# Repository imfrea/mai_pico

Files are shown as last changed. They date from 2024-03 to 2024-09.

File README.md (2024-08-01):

# Mai Pico - Maimai Style Mini Controller
### The purpose of this fork is to provide more detailed production documents, material lists, and casing designs (in Chinese language).
[点这里可以切换到中文版](README_CN.md)

  


**Features:**
* Made with a 15.6 inch portable screen.
* Arcade-like experience.
* Dual-player is possible.
* Built-in AIME support.
* All source files open.

Thanks to many respectful guys/companies who made their tools or materials free or open source (KiCad, OnShape, InkScape, Raspberry things, JLCPCB).

## Notes
This project is the most complex one among all my projects.
* It needs a custom etched ITO glass and a portable display.
* Heavily depends on 3D printing.
* Requires skills to solder tiny components.
* Requires many other DIY hands-on skills.
* The IO PCB is still in prototype state, it works, but the layout and connectors are not perfect. You may need to solder directly from Pi Pico's pins. I'm just too lazy to release a new version.
* I didn't design the housing, so it's your job to make it look nice and structually stable, follow your imagination and taste.

## Check Out My Other Projects
You can also check out my other cool projects.










* Popn Pico: https://github.com/whowechina/popn_pico
* IIDX Pico: https://github.com/whowechina/iidx_pico
* IIDX Teeny: https://github.com/whowechina/iidx_teeny
* Chu Pico: https://github.com/whowechina/chu_pico
* Mai Pico: https://github.com/whowechina/mai_pico
* Diva Pico: https://github.com/whowechina/diva_pico
* AIC Pico: https://github.com/whowechina/aic_pico
* Groove Pico: https://github.com/whowechina/groove_pico

## **Disclaimer** ##
I made this project in my personal time with no financial benefit or sponsorship. I will continue to improve the project. I have done my best to ensure that everything is accurate and functional, there's always a chance that mistakes may occur. I cannot be held responsible for any loss of your time or money that may result from using this open source project. Thank you for your understanding.

## About the License
It's CC-NC. So DIY for yourself and for your friend, don't make money from it.

## Builds Gallery
Before we start, I want to encourage you with some hobbyist builds.

### **Lavide's Build**
  Lavide made a nice compact all-in-one Mai Pico cab!  
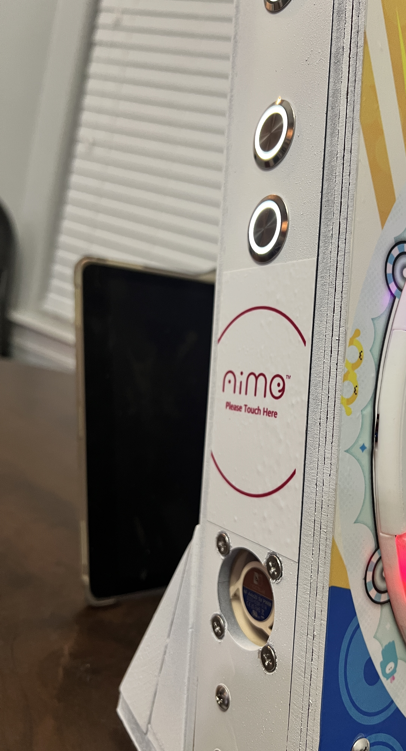
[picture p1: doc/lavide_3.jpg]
  

### **Romper's Build**
  Romper made a full-size con using Mai Pico's touch design.  
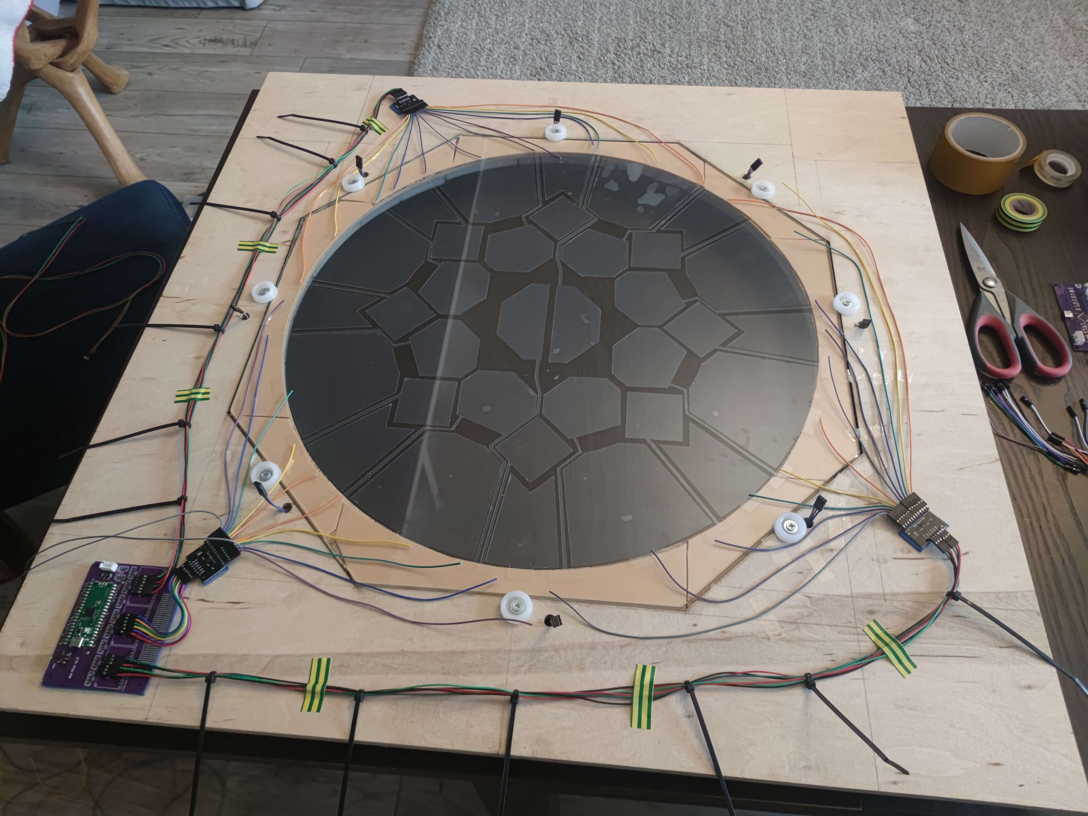
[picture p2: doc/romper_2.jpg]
    
  Check out his build guide here.  
  https://github.com/ir0nq/maimai-homemade-controller

### **imfrea's Build**
  imfrea designed a nice-looking and inexpensive acrylic housing for Mai Pico.  
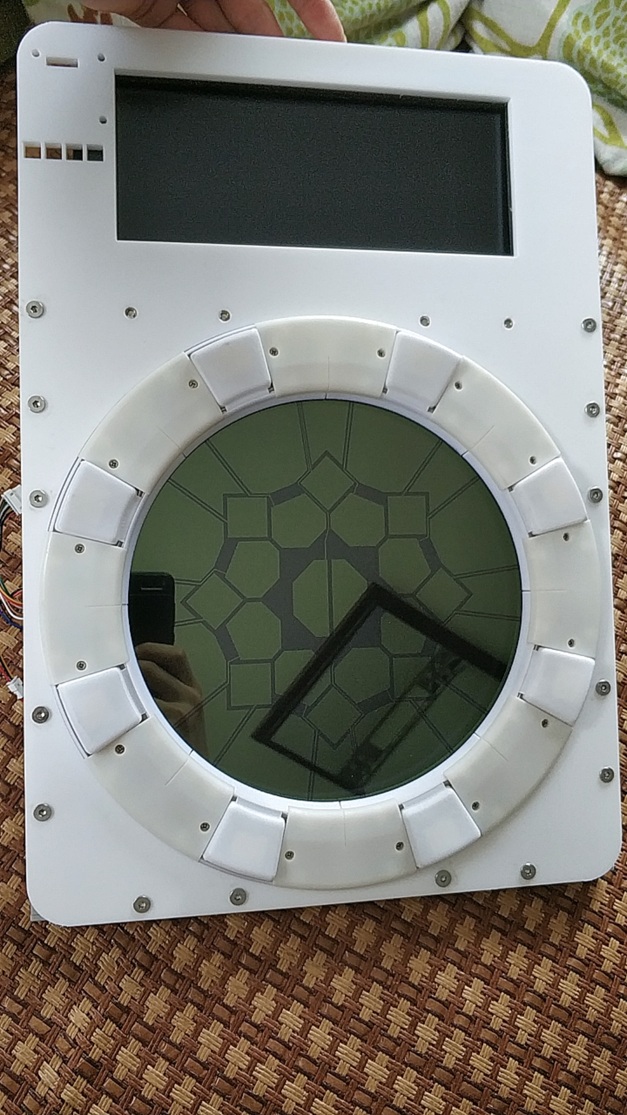
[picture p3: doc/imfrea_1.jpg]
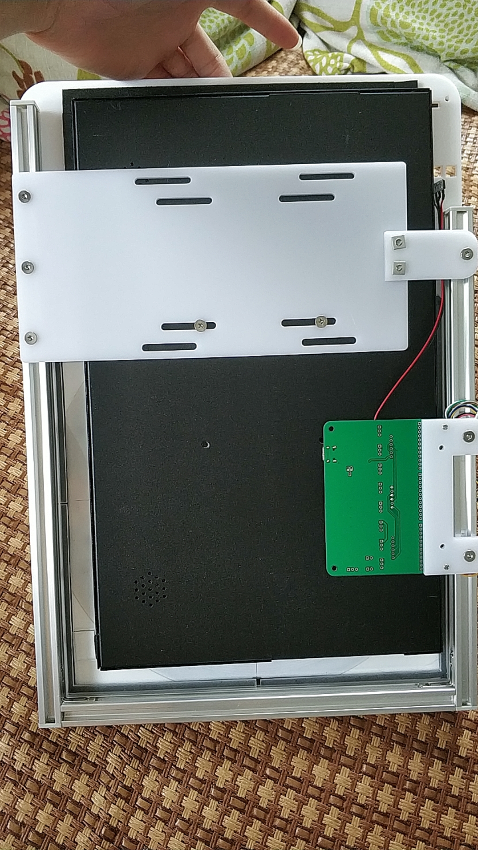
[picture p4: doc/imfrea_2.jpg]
    
  You can download the acrylic case designs from his fork of Mai Pico here.  
  https://github.com/imfrea/mai_pico

## HOW TO BUILD
### PCB
* Go JLCPCB and make order with the gerber zip file (latest `Production\PCB\mai_io_v*.zip` and `Production\PCB\mai_button_v*.zip`), regular FR-4 board, 1.6mm thickness. You need 1x io PCB and 8x button PCBs for one Mai Pico con.  
  
* 1x Rasberry Pico Pi Pico or Pico W.  
  https://www.raspberrypi.com/products/raspberry-pi-pico
  Becareful of 3 pins that are at the other side, they're difficult to solder and may leave air bubbles.  
  
* 1x USB Type-C socket (918-418K2023S40001 or KH-TYPE-C-16P)
* 2x 0603 5.1kohm resistors (R20, R21) for USB. If you plan to use the native USB socket on the Pi Pico directly, then the Type-C socket and resistors can be omitted, making the soldering much simpler.
* 3x MPR121 modules, there're many types in the market, choose ones like this.  
  https://www.sparkfun.com/products/retired/9695  
  Before solder MP121 module to the main PCB board, remember to use a knife to **cut (unshort) the tiny trace that connects ADDR to the GND**. Please be careful not to cut more than necessary.  
  
* Leave U5, U6, U7 area discrete components empty as we're using MPR121 module, not the chip.
* 1x SN74LV1T34DBVR (SOT-23-5) level shifter (U8), if you can't find one, use a 0603 10ohm resistor (R4) as an alternative.  
  https://www.lcsc.com/product-detail/Buffer-Driver-Transceiver_Texas-Instruments-SN74LV1T34DBVR_C100024.html
* 4x 0603 1uF (0.1~1uF all fine) capacitors (C1, C2, C3, C7), OPTIONAL, recommended.
* 16x WS2812B-3528 RGB LEDs (each button needs two).
* 8x Kailh Choc v1 key switches, linear, 30gf to 45gf ones.  
  https://www.kailhswitch.com/mechanical-keyboard-switches/low-profile-key-switches/burnt-orange-switch.html
* 1x PN532 NFC module and some thin wires, only needed if you want AIME.  
  https://www.elechouse.com/product/pn532-nfc-rfid-module-v4/  
  You need to solder it to the same I2C as the MPR121 (GPIO 6 and 7).

### ITO Glass
* Find a service to make custom etching ITO coated glass. The AutoCAD file is `Production\CAD\mai_pico_ito_v*.dwg`. Use 2mm thickness, 10-20ohm sheet resistance ITO coated glass.
  
* The ITO coated glass is connected to the IO PCB by "zebra cable" (1.6mm pitch: 0.8mm black part and 0.8mm clear part). A silicon heater head at 200°C is used to stick the zebra cable to the gold finger part of PCB and ITO coated glass. The formal name of this cable is "Heat Seal Connector".  
  
* Custom ITO coated glass is relatively expensive, but ours is small, so it's not like arcade-size expensive. This is the shop I ordered the ITO glass. The minimal batch is around 5 pieces. But they provide service only in China as far as I know.  
  https://shop378788148.taobao.com/?spm=2013.1.1000126.2.305e16c4LFf1GW

### Button Ring
* Print out the 8x set of base, link, button and cover from `Production\3DPrint\mai_*.stl`.
* Buy 8x 2mm (diameter) * 40mm (length) steel shafts, they're used as the button hinge.
* Here's how to assemble them, hinge shaft and components on PCB are not shown in this rendered image.  
  
* Here's how I assembled the ring. Please note that wiring for the button switches is missing in these pictures.
  * All discrete components ready.  
    
  * Solder the button PCB first.  
    
  * Button PCBs are daisy-chained using short and soft 3-wire cable, they're G, IN/OUT, V (GND, Signal In/Out and VCC respectively). RGB signal goes in from "IN" and goes out to the next LED through "OUT". The "Btn" button signal pins are not soldered yet, you can later wire them. Don't worry about the order of button GPIOs, because they can be remapped through command line interface.    
    
  * You need 3M5423 UHMW film tape (or similar hard and super-smooth PTFE tape with 0.2-0.3 thickness). It is to lubricate the button surface that touches the keyswitch.  
    
  * Assemble the 3D printed parts together with the PCBs.  
    
  * Use shaft to expand the support holes a little bit, and apply some keyboard switch lubricant such as Krytox 205G0 to make the shaft super smooth.  
    
  * Each `link` needs 8x M2*4mm screws to connect two `base`s together.  
    
  * Install the cover, each needs 2x M2*5mm screws.  
    

### Portable Display
  * Resolution: 1920*1080, size: 15.6inch, refresh rate: 120Hz (recommended) or 60Hz, built-in speakers.
  * They're easy to find. Choose cheap or even tiny-flawed ones, they're much cheaper and work just fine.
  * There're 2 types of driver board, one is micro-HDMI only and the other supports type-C display (for convenient Nintendo Switch connection). They're both OK.  
  https://www.amazon.com/s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

### Glue Things Together
  * I use 3M VHB tape (0.5mm or 1mm thickness) to stick the button ring, the ITO glass and the monitor together.
  * Only use a little tape, I use 4 small pieces to stick ITO glass to the display and another 4 small pieces to stick button ring to the ITO glass.
  * Don't apply the tape on the traces of the ITO glass, you can see the traces or pads at certain angle.

### Housing
  * It's your job to design it and make it look nice.

### Firmware
* UF2 file is in `Production\Firmware` folder.
* For the new build, hold the BOOTSEL button while connect the USB to a PC, there will be a disk named "RPI-RP2" showed up. Drag the UF2 firmware binary file into it. That's it.
* LED and Touch protocols are implemented following Sucareto's research at https://github.com/Sucareto/Mai2Touch.
* It has a command line to do configuration. You can use this Web Serial Terminal to connect to the USB serial port of the Mai Pico. (`?` to display help message.)  
  https://googlechromelabs.github.io/serial-terminal/  
  
   * Please note that when you click "Connect" button, you'll actually see the name of each port.  
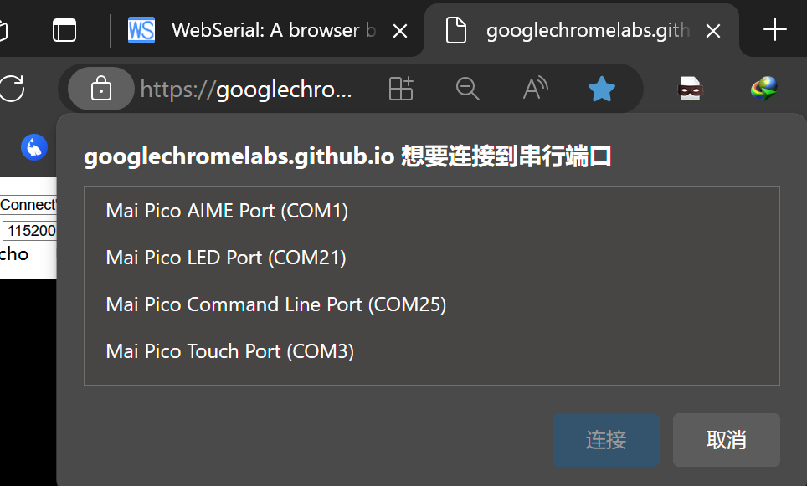
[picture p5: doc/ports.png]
   
* Button GPIOs can be remapped using `gpio` command. Firmware supports 8 main buttons on the ring and 4 auxiliary buttons (Test, Service, Navigate and Coin).
* Touch keys can be remapped using `touch` command. For people who's using Mai Pico to drive a custom ITO film or a ITO glass, this command will be very useful. For example:
  * `touch` with no parameter is to detect touched keys.
  * `touch 1 9 E6` is to set the second MPR121's electrode 9 to key "E6". Key name of "XX" means "Not Connected".
* Daisy chained RGB LED numbers for each button can be assigned using `rgb` command.
* LED brightness can be adjusted by `level` command.
* There are MPR121 parameter tuning and sensitive settings, explore them yourself.
* It implements 3 COM ports, one is for command line and the other two are for LED and Touch. By issuing `whoami` to the command line, each COM port will print their identities.
* Button signal is sent to the host by HID Joystick or HID NKRO (keyboard). There're two set of NKRO keymaps, use `hid <joy|key1|key2>` to switch between them. In NKRO mode, key mappings are:
  * key1: `WEDCXZAQ`-Ring Buttons, `3`-Select
  * key2 (Numpad): `89632147`-Ring Buttons, `*`-Select
  * Above two sets both have: `F1`-Test `F2`-Service `F3`-Coin
* `factory` to reset to default. When there's a firmware update, the old configuration may become corrupted, you can reset configuration, then re-plug the controller.

## CAD Source File
I'm using OnShape free subscription. It's powerful but it can't archive original designs to local, so I can only share the link here. STL/DXF/DWG files are exported from this online document.  
https://cad.onshape.com/documents/d8b39d27c9cb7990d9ce4d46/w/2c1baa71e391bfd1246f122b/e/f87f0f1c373fe2186ddc5c9c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

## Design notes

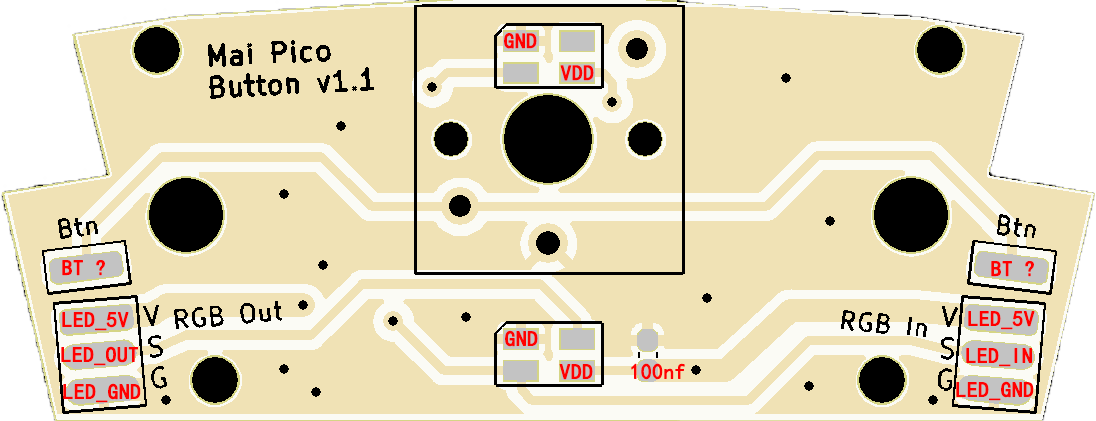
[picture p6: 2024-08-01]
doc/button_v111_top.png

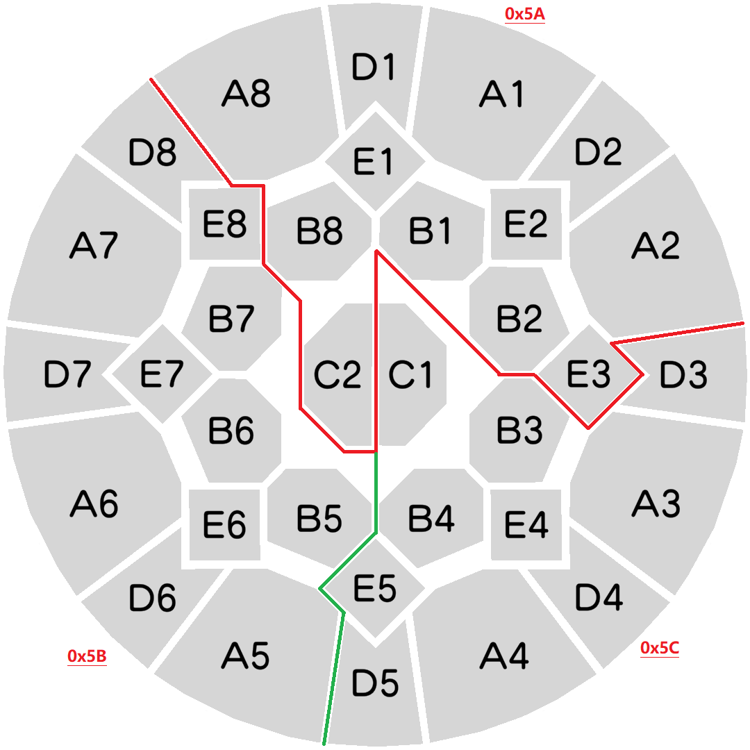
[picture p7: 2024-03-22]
doc/mpr121_electrode.png

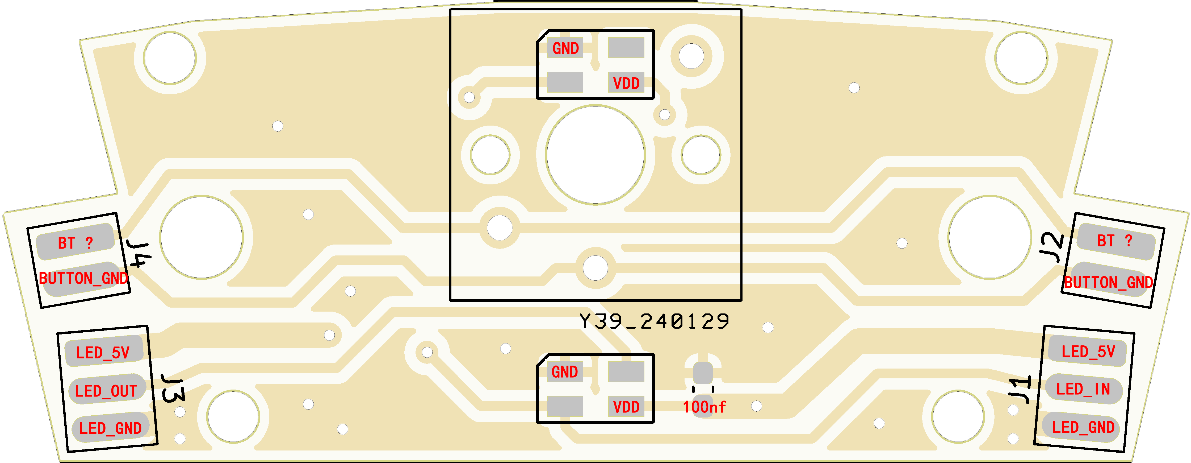
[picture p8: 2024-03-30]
doc/button_v1_top.png

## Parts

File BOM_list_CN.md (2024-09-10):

### 物料清单

* 电子元件部分

| 序号 | 名称 | 规格 | 库位 | 所需数量 | 参考价格 | 重要性 | 备注 |
| ---- | --- | --- | --- | --- | --- | --- | --- |
| 1 | mai_io_v1  PCB | FR-4  2层 1.6mm厚 | | 1 | 20￥/5片 | 必要 | 不需要确认生产稿\|单片出货\|添加嘉立创客编-无要求\|不需要SMT贴片\|不需要开钢网 |
| 2 | mai_button_v111  PCB  | FR-4  2层 1.6mm厚 白色阻焊 | | 8 | 25￥/10片 | 必要 | 同上，其余选项请保持默认 |
| 3 | 树莓派 Pico | 不焊接排针 | U1 | 1 | 15.8￥/片 | 必要 | 购买无后缀的Pico，除非你正好有Pico W |
| 4 | Type-C母座 | 918-418K2023S40001 / KH-TYPE-C-16P | USB1 | 1 | 0.23￥/颗 | 可选 | 别名：16p贴片 4脚直插 |
| 5 | 5.1k 电阻 | 0603 精度5%或1%均可 | R20 R21 | 2 | 0.8￥/100颗 | 可选 | |
| 6 | MPR121 模块 | | U5 U6 U7 | 3 | 14.7￥/3片 | 与MPR121芯片**二选一** | |
| | 2.54mm 短排针 | 7.5mm 单排 6Pin 与12Pin | | 3+3 | 5.5￥/6Pin 12Pin各10个（或仅12Pin*12个） | 可选，与MPR121芯片**二选一** | MPR121模块附带的排针较长，可剪短，或额外购买短排针 |
| 7 | MPR121QR2 芯片 | QFN20 | U2 U3 U4 | 3 | 6.39￥/3颗 | 与MPR121模块**二选一** | 用于分立电路 |
| 8 | 75k 电阻 | 0603 | R1 R2 R3 | 3 | 0.8￥/100颗 | 与MPR121模块**二选一** | 用于分立电路 |
| 9 | 0.1uF 电容 | 0603 耐压16V（以上） 精度±10% | C4 C5 C6 C8 C9 C10 | 6 | 1.5￥/50颗 | 与MPR121模块**二选一** | 用于分立电路 |
| 10 | 0.1uF 电容 | 0603 | C1 C2 C3 C7 | 4 | 占位，勿重复购买 | 可选（推荐） | 别名：100nf 104 |
| 11 | 10r 电阻 | 0603 | R4 | 1 | 0.8￥/100颗 | 可选（与SN74LV1T34**二选一**） | |
| 12 | SN74LV1T34DBVR 芯片 | SOT-23-5 | U8 | 1 | 0.49/颗 | 可选（与10r电阻**二选一**） | |
| 13 | 0.1uF 电容 | 0603 | | 8 | 占位，勿重复购买 | | 用于按键板 |
| 14 | WS2812B  RGB LED | 3528 | | 16 | 2.54￥/16颗 | | 注意是**3528**封装，型号WS2812B，而非普通RGB灯珠 |
| 15 | 凯华 Choc v1 轴体 | 线性 30gf 到 45gf | | 8 | 28￥/10颗 | | 别名：巧克力 v1 猪鼻 白轴 矮轴（描述词有差异 以实物图片为准） |
| | NFC模块 | PN532 | | 1 | 12.4￥/片 | 可选 | |

* 结构件与五金件

| 序号 | 名称 | 规格 | 所需数量 | 参考价格 | 重要性 | 备注 |
| ---- | --- | --- | --- | --- | --- | --- |
| 16 | mai_base.stl | | 8 | 同下 | | **慎用SLA光固化工艺**，推荐FDM（层高小于0.2mm）ABS或PETG材料获得最佳性价比与强度 |
| 17 | mai_link.stl | | 8 | 同下 | | **慎用SLA光固化工艺**，推荐FDM（层高小于0.2mm）ABS或PETG材料获得最佳性价比与强度 |
| 18 | mai_button.stl | | 8 | 同下 | | **慎用SLA光固化工艺**，同上，可选SLS激光烧结白色尼龙，可获得更好的表面纹理与强度 |
| 19 | mai_cover.stl  | | 8 | 62￥/本项加以上共32件（ABS） | | 可选SLA光固化工艺，获得最佳的表面纹理与性价比 |
| 20 | 钢轴 | 2mm（直径）* 40mm（长度） | 8 | 2.29￥/50颗 | | 别名：不锈钢销钉 |
| 21 | M2*4mm 螺丝 | | 64 | 1￥/100颗 | | 用于打印件mai_link的安装 |
| 22 | M2*6mm 螺丝 | | 16 | 1￥/100颗 | | 用于打印件mai_cover的安装 |

* 通用

| 序号 | 名称 | 规格 | 所需数量 | 参考价格 | 重要性 | 备注 |
| ---- | --- | --- | --- | --- | --- | --- |
| 23 | ITO 玻璃 | 2mm厚  10-20欧姆方阻 | 1 | 126￥/片 | 必要 | 可咨询该商家近期是否有相同订单在生产，若有，则1片也可以发货。或者到闲鱼上寻找他人多订的存货。 |
| 24 | 斑马线 | 1.6mm 间距 34Pin XX16 | 1 | 9￥/49Pin*210cm | 必要 | 别名：热压导电斑马纸 34Pin以上可**自行剪裁**，总长度建议在**5cm以内**，避免影响触摸灵敏度 |
| 25 | 一些电子线 | 不是必须得用4Pin排线，不宜太粗，28或30AWG均可，建议选择“双头镀锡电子线 4cm” | | | 必要 | 用于按键板与io板之间的连接 |
| 26 | 空中对接线 | 1.25mm  3pin母头+端子线 | 一对 | 3.3￥/5+5条（10cm）  | 可选 | 用于按键板与io板之间的连接 |
| 27 | 空中对接线 | 1.25mm  8pin母头+端子线 | 一对 | 3.33￥/1+1条（15cm） | 可选 | 用于按键板与io板之间的连接 |
| 28 | 成品便携屏（含驱动板） | 分辨率：1920*1080，尺寸：15.6 英寸，刷新率：120Hz（推荐）或 60Hz，内置扬声器。micro-HDMI或Type-C显示接口。 | 1 | | 必要 | 你也可以从头DIY一个15.6寸显示器，本文不详细讨论。如果你有180°开合或360°翻转的15.6寸屏笔记本电脑，若无冲突亦可直接安装于上。 |

* 工具与辅料

| 序号 | 名称 | 规格 | 所需数量  | 参考价格 | 重要性 | 备注 |
| ---- | --- | --- | --- | --- | --- | --- |
| 29 | T型烙铁头（烙铁套装）+橡胶条 | | 1套 | 9.9￥/套 | 必要 | 别名：斑马线热压头 请选择适合自己烙铁的类型，或带烙铁的套装 |
| 30 | 3M5423  UHMW或 PTFE 胶带 | 厚度 0.2-0.3 | 1卷 | | | 用于填充键帽与轴体的空隙（无铺垫材料可能无法触发全部键程）  |
| 31 | 3M VHB 胶带 | | 1卷 | | | 用于粘接按钮环、玻璃以及显示器 |
| 32 | 纤维胶带 | 12mm宽 | 1卷 | | | 用于保护io PCB与玻璃间的斑马线 |
| 33 | 醋酸胶带 | 10mm宽 | 1卷 | 2.16￥/30米 | | 用于包裹ITO玻璃的边缘 |
| 34 | 润滑脂 | Krytox 205G0 | 1罐/盒/瓶 | | | |

* 工具与辅料（未提及）

| 序号 | 名称 | 重要性 | 备注 |
| ---- | --- | --- | --- |
| 41 | 电烙铁 | 必要 | 又称焊台，推荐恒温可调内热式，刀头 |
| 42 | 热风枪 | 可选 | 便于焊接贴片元器件（与PTC发热板二选一） |
| 43 | PTC发热板 | 可选 | 又称LED灯珠拆焊台，便于焊接贴片元器件（与热风枪二选一） |
| 44 | 尖头镊子 | 必要 | 用于夹持小型元器件 |
| 45 | 美工刀 | | 剪裁胶带等 |
| 46 | 斜口钳/剥线钳 | | 用于剪断和剥开线缆 |
| 47 | 螺丝刀 | 必要 | |
| 48 | 万用表 | 推荐 | 用于检测线路通断等 |
| 49 | 焊锡丝 | 必要 | 含铅 63%纯度 0.8mm |
| 50 | 锡浆 | 可选 | 中温183℃，与2、3项搭配使用 |
| 51 | 助焊剂 | 可选 | |
| 52 | 电工胶带/热缩管 | | |

* 外壳（实用经济版）

`免责声明：本人为非专业人士，使用非专业软件设计此外壳，谨慎使用。因理解偏差等原因造成的损失需自行承担，使用本方案视作理解并接受。本人不对DIY成功率作任何保证，亦不提供一对一指导。`

* 本方案利用一整块亚克力激光切割而成，如厂家是按件计费的（CNC加工可能不接受板内有多个组件，或报价较高），请考虑更换厂家。
  * 亚克力的质地较软且容易产生划痕，但成本低易于加工，你也可以采用其他板材（玻纤板、PP板、PVC板等），板材的厚度也可以根据实际情况调整（注意改变板厚会同时要改变螺丝长度）

| 序号 | 名称 | 规格 | 所需数量 | 参考价格 | 备注 |
| ---- | --- | --- | --- | --- | --- |
| 1 | front.dwg 前面板 | 长409 宽282 厚4mm 白色亚克力 | 1片 | 30￥/张 | 内含其他组件1+6共7件 见`\doc\assemble_case_part.jpg` |
| 2 | mid.dwg 中框垫板 | 长292.5 宽236 厚2mm 亚克力（颜色不限） | 1片 | 10￥/张 | 共8小件 |
| 3 | 螺丝 | m4*12 薄头 | 18颗 | 3￥/50颗 | 用于前面板 |
| 4 | 1515欧标铝型材 | 银色 383.5mm | 2条 | 2.11￥/条 | 型材框 |
| 5 | 1515欧标铝型材 | 银色 252mm | 1条 | 1.39￥/条 | 型材框 |
| 6 | 1515端盖 | 灰色 | 4个 | 0.2￥/个 | 用于型材框 |
| 7 | 1515角槽（配螺丝） | | 2个 | 1￥/套 | 用于型材框（注：含4颗m4顶丝） |
| 8 | T形螺母 | 欧标15TM4 | 24颗 | 0.25￥/颗 | 用于型材框 |
| 9 | 螺丝 | m4*8 薄头 | 8颗 | 3.7￥/100颗  | 用于VESA背板及IO PCB安装板 |
| 11 | 螺丝 | m3*5 对锁螺丝 | 6对 | 4.34￥/20对  | 用于io板 PN532模块（注：子母丝成对） |
| 12 | 螺丝 | m4*6 薄头 | 8颗 | 2.93￥/100颗 | 用于前面板、与夹板螺母组合，以及VESA安装孔 |
| 13 | 夹板螺母 | m4*4 **外径5** | 6颗 | 2.38￥/20颗  | 用于前面板和VESA背板（注：仅螺母） |
| 14 | 扳手 | 2.5mm内六角 | 1把 | 1.5￥/把 | M4内六角螺丝使用，实际取决于你以上购买的螺丝类型 |
| 15 | EVA海绵胶 | 4mm厚 宽度≤20mm | 1卷 | | 用于前面板 |
| 16 | sticker.png 装饰贴纸 | 282*118mm | 1张 | | 由“[剪刀Official](https://space.bilibili.com/89636132)”设计 |

* 完整版外壳（以上表为基础）
| 序号 | 名称 | 规格 | 所需数量 | 参考价格 | 备注 |
| ---- | --- | --- | --- | --- | --- |
| 1 | back-full.dwg 背板 | 长409 宽282mm 2mm厚 玻璃纤维  | 1片 | 40￥＜ | 完整背板，兼容成品便携屏，亦支持带锁孔的液晶屏的安装 |
| 2 | cover.dwg 上框保护盖 | 长282 宽119 厚1mm 透明亚克力  | 1片 | 10￥ | 屏幕防尘和盖住贴纸 |
| 3 | 螺丝 | m4*6 薄头 | 8颗 | | 用于完整背板 |
| 4 | m2铜柱 | 双通 m2*12mm | 8颗 | | 用于带锁孔的液晶屏安装 |
| 5 | 螺丝 | m2*6 勿重复购买 | 16颗 | | 用于带锁孔的液晶屏安装 |
| 5 | EVA海绵胶 | 同上表，勿重复购买，叠2层使用 | | | 用于液晶屏底部 |

* 如果你是触屏流玩家，且不考虑制作按键环，则可以节约100￥的成本和大部分的工序（但你将同时失去灯光和圆形边框）。
  
  * 不制作按键环，以上表格中的第2，11，12，13，14，15；25，26，27，34项，表格 “结构件与五金件” 内的全部项目都无需购买。
  
* 价格可能随市场行情波动，以上报价（正常价格含邮费）仅供参考，供货商的不同，最小起订量也将不同。

* 购买电子元件，请尽量选择品类丰富齐全，价格合理的店铺，特别是运费低或包邮门槛低的店铺（减少不必要的运费损耗），但也不要一味追求一站式配齐。

  购买数量刚好覆盖需求即可，亦可适当多备几件。

* 如果你第一次使用嘉立创，请不要错过领取和使用立创商城（购买元件）和3D打印服务的新人优惠券。使用<u>嘉立创下单小助手（客户端）</u>下单才能享受优惠。

* 由于非立创EDA格式Gerber文件不能享受免费打样，有两种节约策略：~~①当月付费（20元）先下单5片按键PCB，次月即可领取2张通用格式免费打样优惠券，再分别0元下单io PCB和另外的5片按键PCB（返单），可最小化开销（共3次打样，等待时间长）。或者~~②一次性下单10片按键PCB（不包邮，需支付5元快递费），次月再领取通用格式优惠券下单io PCB（共2次打样，等待时间短，推荐这种）。③使用 `\Production\PCB` 下的 `xxx_JLC_format.zip` 文件打样（该文件使用[FuckJLC](https://github.com/acha666/FuckJLC)转换）。
  
  * 如遇<u>审核拆单嫌疑</u>，请勿付款。先取消订单，尝试次日换个时间段下单，或使用KiCad编辑PCB源文件添加任意丝印后导出Gerber。

* [捷配](https://www.jiepei.com/pcb/pcbquote)也可以提供PCB免费打样服务（数量3片）且不限制Gerber文件，适合下单io PCB（手动填写长宽，层数等信息，加入购物车，最后上传Gerber）。

* 如果你没有合适的3D打印机或耗材，需要3D打印服务可选择嘉立创3D打印（SLA和SLS等工艺），对于FDM工艺则可以选择淘宝商家，价格更实惠，或者请你的朋友帮忙打印。

* 市面上售卖的树莓派Pico（RP2040）有很多厂家的不同版本，它们在元件布局，引脚点位，颜色甚至芯片方案都存在差异，请注意购买单面元件的邮票孔模块，背面USB位置引出3个焊盘（TP1 TP2 TP3）的版本（如果没有，你将只能把数据线直接插在开发板本体上），要与原版相兼容，或者认准官方原版。

* 如果你不使用MPR121模块，而是焊接分立元件，则除了3颗MPR121 QFN20芯片外还需要3颗75k 0603电阻，和额外的6颗100nf 0603电容。只建议具备工具条件（LED拆焊台或热风枪）且焊接经验丰富的人这么做（注意控制温度和焊接时间），分立元件在成本和体积厚度上有优势。

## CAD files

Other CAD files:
Production/Case/back-full.dwg
Production/Case/mid.dwg
Production/Case/front.dwg
Production/Case/cover.dwg

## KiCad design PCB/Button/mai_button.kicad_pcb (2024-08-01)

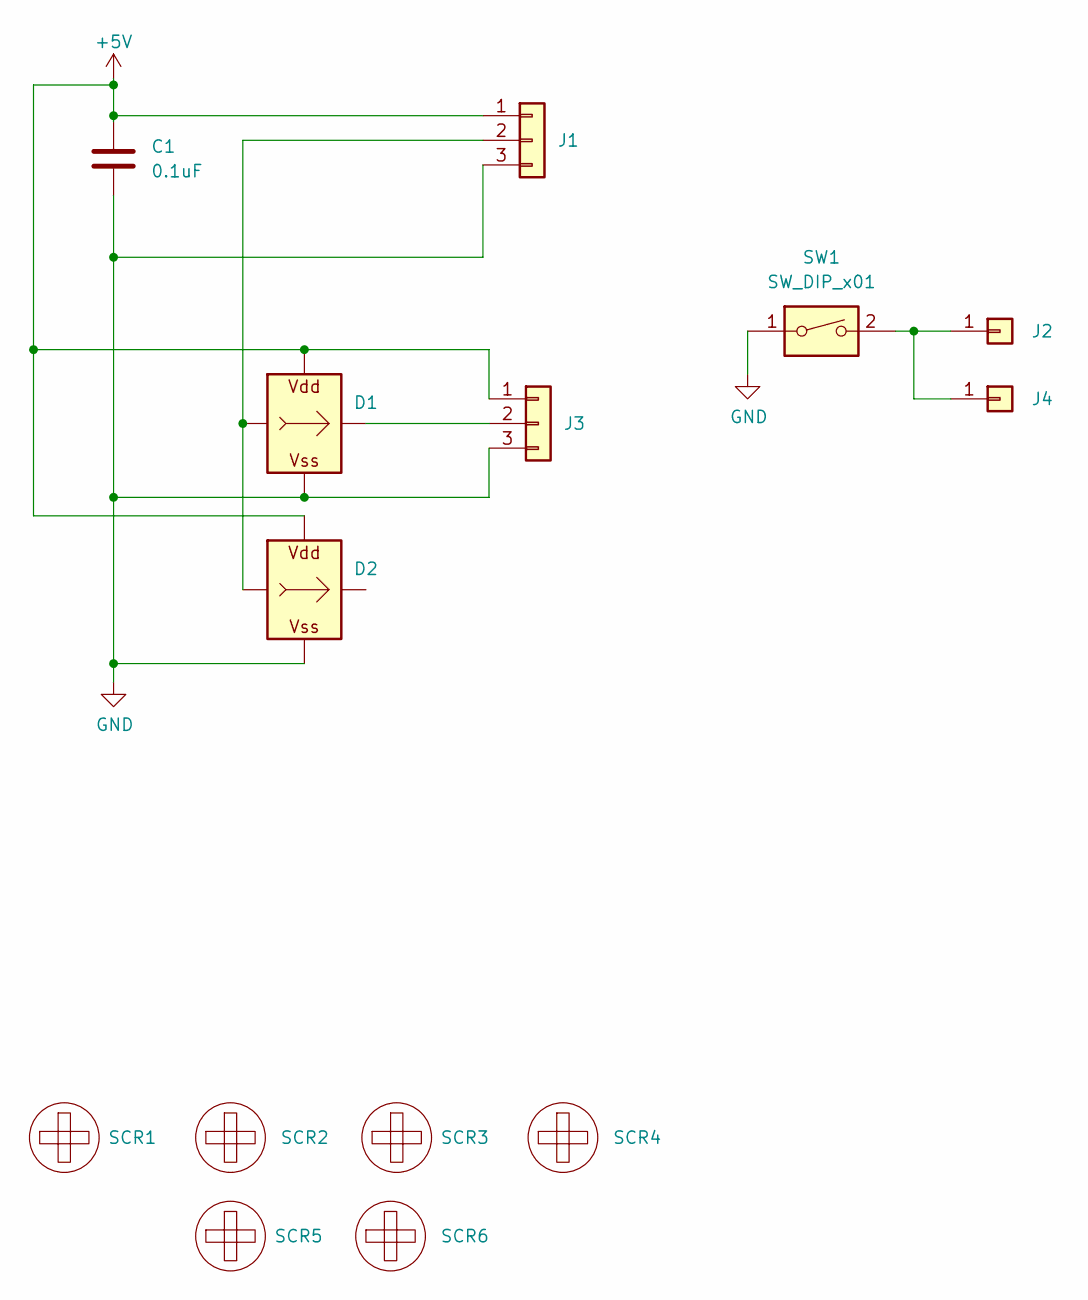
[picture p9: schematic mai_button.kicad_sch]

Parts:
C1: 0.1uF; C_0603_1608Metric_Pad1.08x0.95mm_HandSolder
D1, D2: WS2812B_Unified; WS2812B-2835
J1: RGB In; Solder_3P
J2, J4: Btn; Solder_1P
J3: RGB Out; Solder_3P
SCR1, SCR2, SCR3, SCR4: ScrewHole; Hole2.5
SCR5, SCR6: ScrewHole; Hole4.0
SW1: SW_DIP_x01; SW_Kailh_Choc_V1V2_1.00u_LED

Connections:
+5V: C1.1, D1.V (VDD), D2.V (VDD), J1.1, J3.1
GND: C1.2, D1.G (VSS), D2.G (VSS), J1.3, J3.3, SW1.1
unnamed: D1.I (In), D2.I (In), J1.2
unnamed: D1.O (Out), J3.2
unnamed: J2.1, J4.1, SW1.2

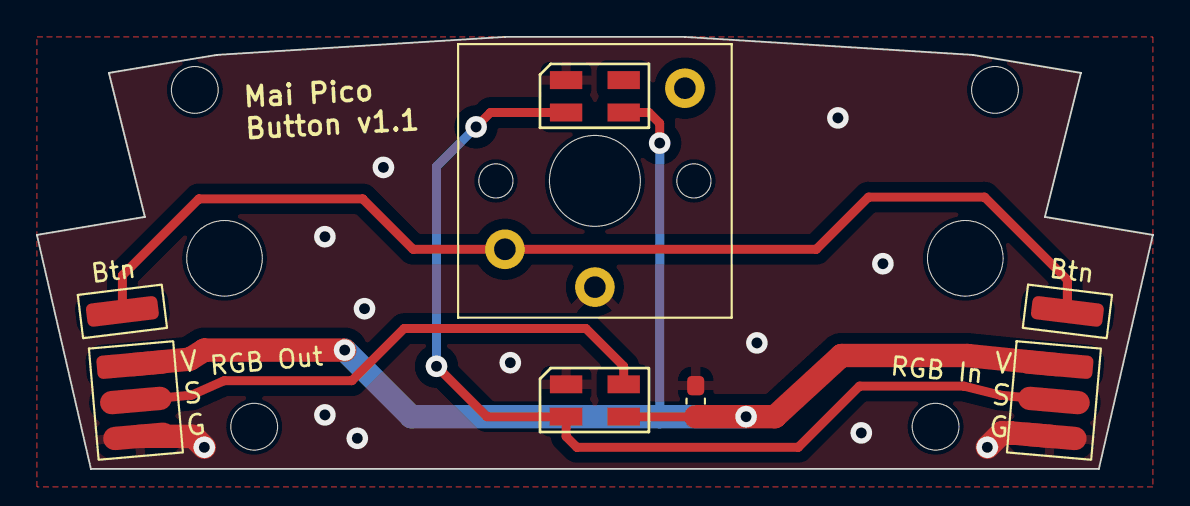
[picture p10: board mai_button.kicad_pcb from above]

Board: 2 copper layers, 62.0 x 24.0 mm, 14 parts (0 on the bottom side), 5 nets.

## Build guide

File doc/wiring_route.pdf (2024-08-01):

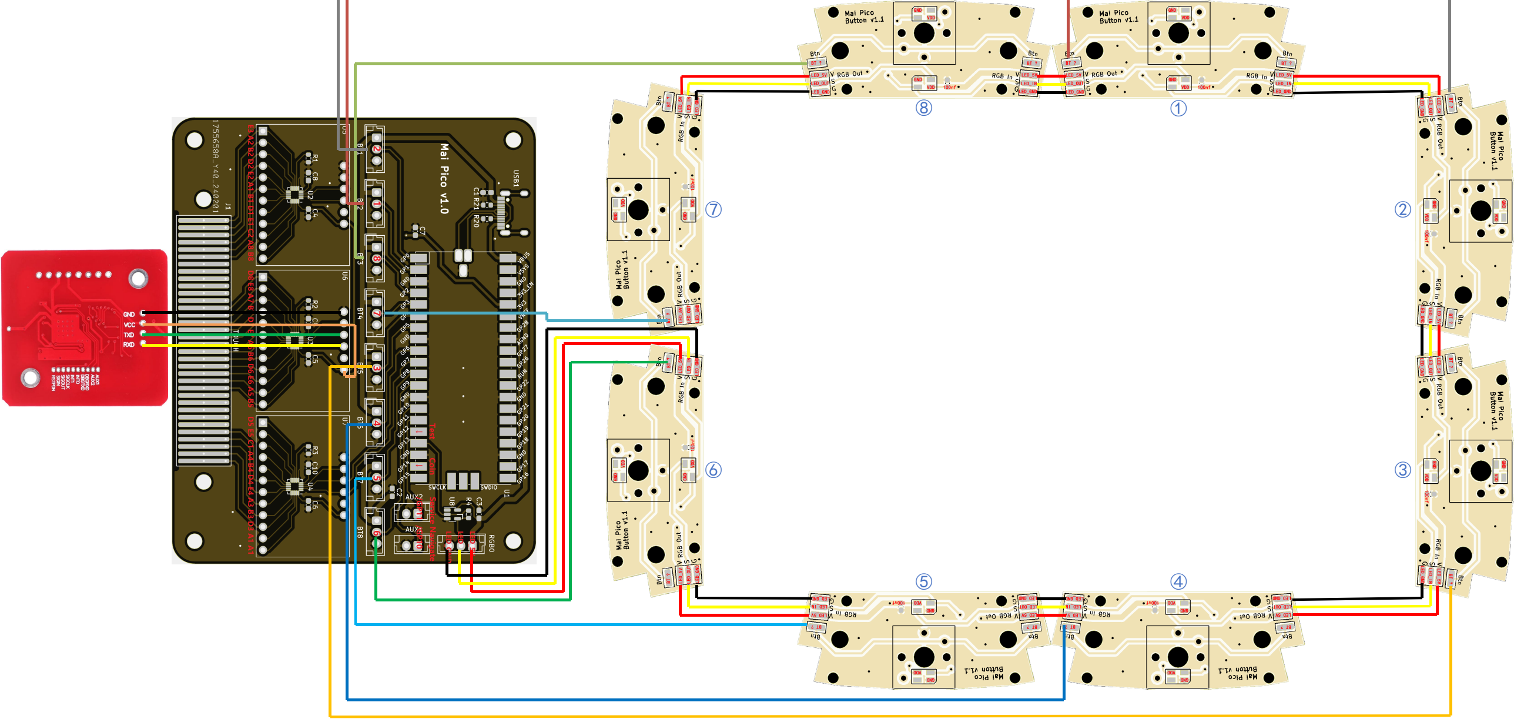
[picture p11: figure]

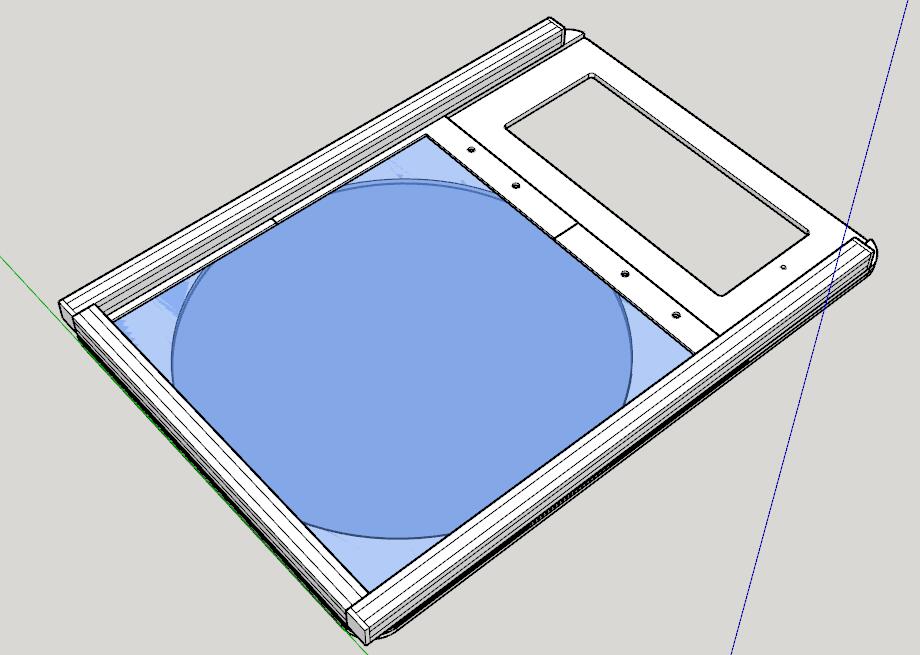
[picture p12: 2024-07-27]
doc/assemble_case_third_layer.jpg

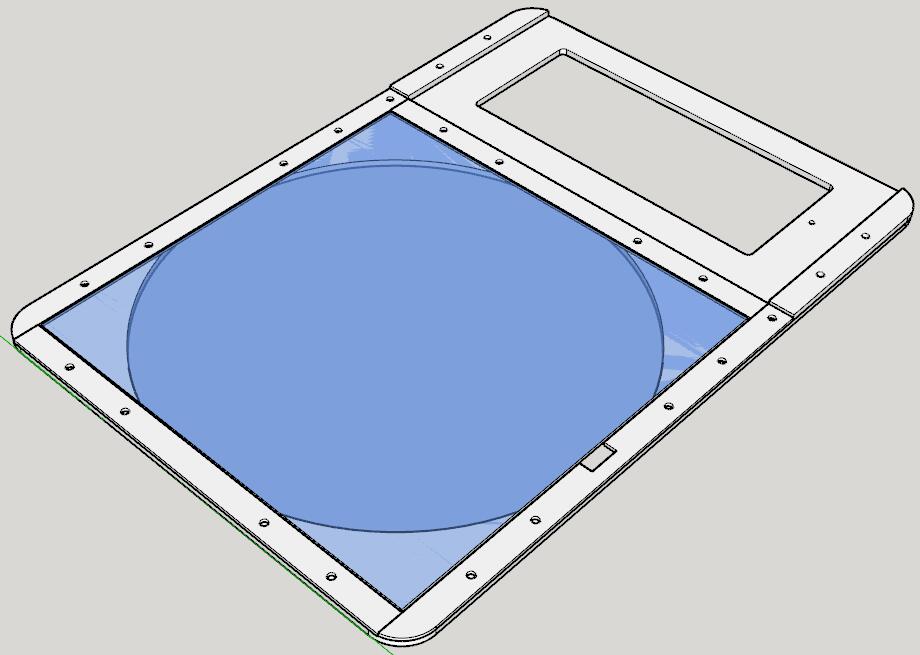
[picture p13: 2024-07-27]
doc/assemble_case_first_layer.jpg

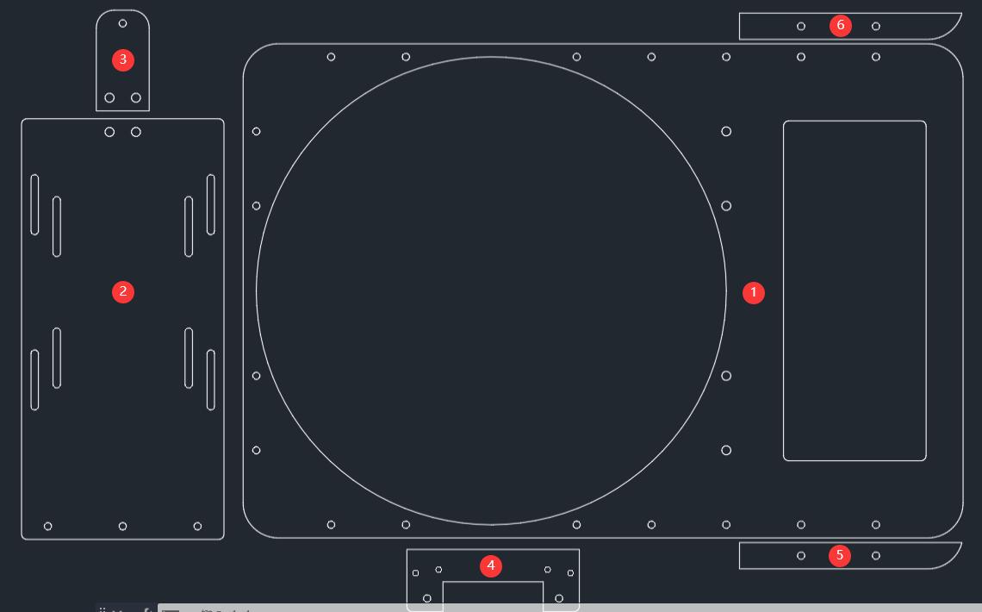
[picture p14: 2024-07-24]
doc/assemble_case_part.jpg

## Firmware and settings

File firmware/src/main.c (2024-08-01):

/*
 * Controller Main
 * WHowe <github.com/whowechina>
 */

#include <stdlib.h>
#include <stdint.h>
#include <stdbool.h>

#include "pico/stdio.h"
#include "pico/stdlib.h"
#include "bsp/board.h"
#include "pico/multicore.h"
#include "pico/bootrom.h"

#include "hardware/gpio.h"
#include "hardware/sync.h"
#include "hardware/structs/ioqspi.h"
#include "hardware/structs/sio.h"

#include "tusb.h"
#include "usb_descriptors.h"

#include "aime.h"
#include "nfc.h"

#include "board_defs.h"

#include "touch.h"
#include "button.h"
#include "rgb.h"

#include "save.h"
#include "config.h"
#include "cli.h"
#include "commands.h"
#include "io.h"
#include "hid.h"

static void button_lights_clear()
{
    for (int i = 0; i < 8; i++) {
        rgb_set_button(i, 0, 0);
    }
}

static void button_lights_rainbow()
{
    static uint16_t loop = 0;
    loop++;
    uint16_t buttons = button_read();
    for (int i = 0; i < 8; i++) {
        uint8_t phase = (i * 256 + loop) / 8;
        uint32_t color;
        if (buttons & (1 << i)) {
            color = rgb32_from_hsv(phase, 64, 255);
        } else {
            color = rgb32_from_hsv(phase, 240, 20);
        }
        rgb_set_button(i, color, 0);
    }
}

static void run_lights()
{
    static bool was_rainbow = true;
    bool go_rainbow = !io_is_active() && !aime_is_active();

    if (go_rainbow) {
        button_lights_rainbow();
    } else if (was_rainbow) {
        button_lights_clear();
    }

    was_rainbow = go_rainbow;
}


const int aime_intf = 3;
static void cdc_aime_putc(uint8_t byte)
{
    tud_cdc_n_write(aime_intf, &byte, 1);
    tud_cdc_n_write_flush(aime_intf);
}

static void aime_run()
{
    if (tud_cdc_n_available(aime_intf)) {
        uint8_t buf[32];
        uint32_t count = tud_cdc_n_read(aime_intf, buf, sizeof(buf));

        for (int i = 0; i < count; i++) {
            aime_feed(buf[i]);
        }
    }
}
static mutex_t core1_io_lock;
static void core1_loop()
{
    while (1) {
        if (mutex_try_enter(&core1_io_lock, NULL)) {
            run_lights();
            rgb_update();
            mutex_exit(&core1_io_lock);
        }
        cli_fps_count(1);
        sleep_ms(1);
    }
}

static void core0_loop()
{
    uint64_t next_frame = time_us_64();

    while(1) {
        tud_task();
        io_update();

        cli_run();
        aime_run();
        save_loop();
        cli_fps_count(0);

        sleep_until(next_frame);
        next_frame += 1000; // 1KHz

        touch_update();
        button_update();

        hid_update();
    }
}

void init()
{
    sleep_ms(50);
    set_sys_clock_khz(150000, true);
    board_init();

    tusb_init();
    stdio_init_all();

    config_init();
    mutex_init(&core1_io_lock);

    save_init(board_id_32() ^ 0xcafe1111, &core1_io_lock);

    touch_init();
    button_init();
    rgb_init();

    nfc_attach_i2c(I2C_PORT);
    nfc_init();
    aime_init(cdc_aime_putc);
    aime_set_mode(mai_cfg->aime.mode);
    aime_virtual_aic(mai_cfg->aime.virtual_aic);

    cli_init("mai_pico>", "\n   << Mai Pico Controller >>\n"
                            " https://github.com/whowechina\n\n");
    commands_init();

    mai_runtime.key_stuck = button_is_stuck();
}

int main(void)
{
    init();
    multicore_launch_core1(core1_loop);
    core0_loop();
    return 0;
}

// Invoked when received GET_REPORT control request
// Application must fill buffer report's content and return its length.
// Return zero will cause the stack to STALL request
uint16_t tud_hid_get_report_cb(uint8_t itf, uint8_t report_id,
                               hid_report_type_t report_type, uint8_t *buffer,
                               uint16_t reqlen)
{
    printf("Get from USB %d-%d\n", report_id, report_type);
    return 0;
}

// Invoked when received SET_REPORT control request or
// received data on OUT endpoint ( Report ID = 0, Type = 0 )
void tud_hid_set_report_cb(uint8_t itf, uint8_t report_id,
                           hid_report_type_t report_type, uint8_t const *buffer,
                           uint16_t bufsize)
{
    hid_proc(buffer, bufsize);
}

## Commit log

2024-03-06 simple models to link and fold io PCB
    [PCB_fold_left.stl, PCB_fold_main.stl, PCB_fold_right.stl]
2024-03-08 update BOM list
2024-03-10 more details about wiring
2024-03-20 update document
    [PCB_fold_left.stl, PCB_fold_right.stl]
2024-03-30 added wiring_route.pdf
2024-04-05 update materials and wiring
2024-07-23 casing manufacture file and BOM
    [PCB_fold_left.stl, PCB_fold_main.stl, PCB_fold_right.stl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]
2024-07-24 fixes and document
    [mid.dwg]
2024-07-27 fixes and images
    [front.dwg, mid.dwg]
2024-07-28 little fixes
    [front.dwg]
2024-08-01 update wiring and pictures, JLC format Gerber
2024-08-12 NFC module hole fix,reference price
    [front.dwg]
2024-09-09 full back panel, sub-monitor cover and some optimizations
    [back-full.dwg, cover.dwg, front.dwg]
2024-09-10 re-upload files
    [back-full.dwg, mid.dwg]
